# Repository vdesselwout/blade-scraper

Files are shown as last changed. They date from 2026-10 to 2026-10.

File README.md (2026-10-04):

<!-- Keep this README in step with the releases: see "Updating this README" at the bottom. -->

# Blade scraper

A 3D-printed razor scraper for standard trapezoid utility blades (61 mm cutting edge). Use it on glass, tiles, labels and paint. It has four PLA parts and needs no screws, other hardware or supports.

**Current version: v7** · [download the latest release](https://github.com/vdesselwout/blade-scraper/releases/latest) · [on Printables](https://www.printables.com/model/1865739-razor-blade-scraper-with-spare-blade-drawer-no-scr) · v7 changes only the guard, which now holds on to the handle instead of the cap. v7 is test-printed: the guard slides on and holds, though it comes off a little easily

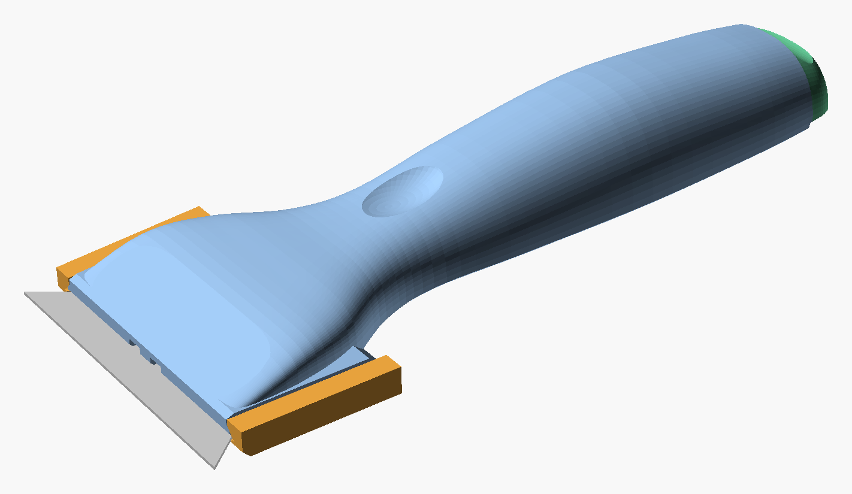
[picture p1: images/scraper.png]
The scraper with a blade fitted


| Guard on | Spare-blade drawer open |
|---|---|
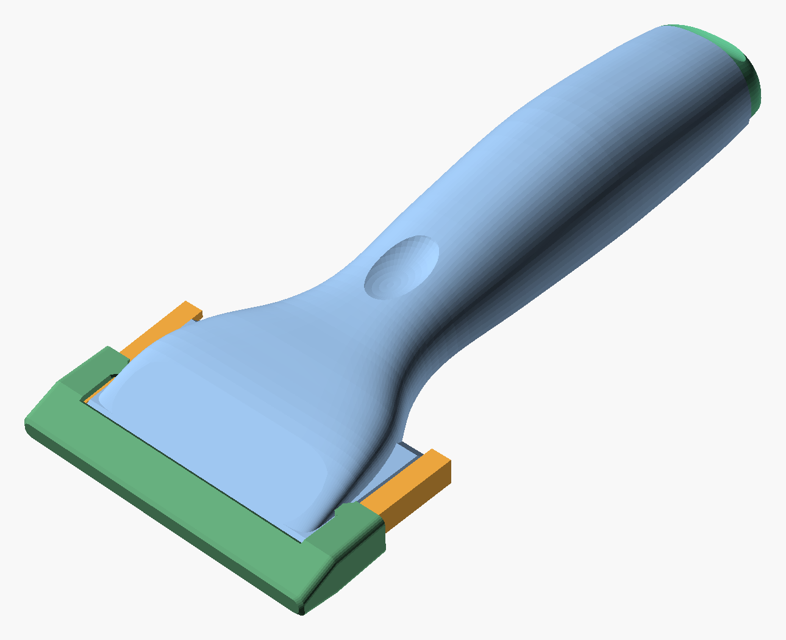
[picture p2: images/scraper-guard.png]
The scraper with the open-top guard fitted
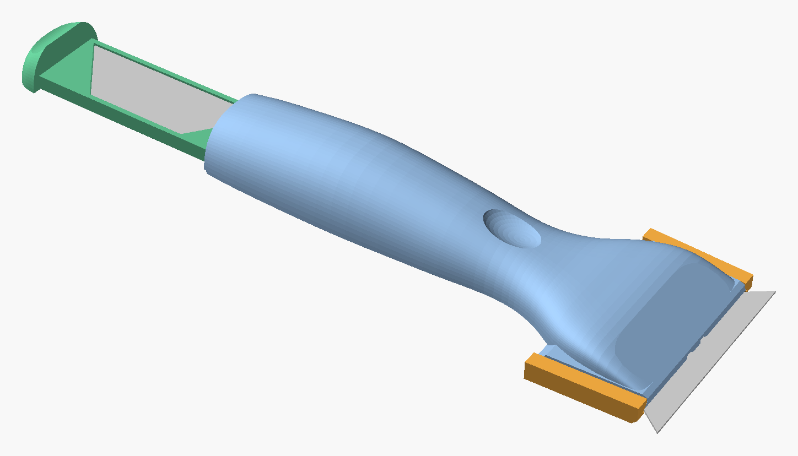
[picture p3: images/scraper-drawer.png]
The blade drawer pulled out of the handle, holding spare blades
|  |  |

## Features

- **No-tool blade change:** the blade sits on two pegs that go through its notches. The cap slides onto the head on dovetails and clamps the blade, and a small snap stops it creeping forward.
- **Spare blades in the handle:** a drawer slides out of the butt and holds 5 blades flat, with their edges enclosed. It "clicks" shut.
- **Slim guard:** an open-top guard covers the exposed edge and leaves the head visible. It grips the head, not the cap, so taking it off never pulls the cap and blade with it.
- **Size:** 155.5 mm long, with a 31 × 19 mm palm swell. The full set uses about 38 g of PLA.

## Printing

Each [release](https://github.com/vdesselwout/blade-scraper/releases) has three files:

- `scraper-vN.stl`: all parts laid out on one bed
- `scraper-vN.3mf`: the same layout as a Creality Print project, with print settings included
- `scraper-vN-parts.zip`: each part as its own STL

Print in PLA with a 0.4 mm nozzle, 2 walls and 15% infill. Print every part as laid out; no supports are needed. The guard stands on its nose with its open end up; if it comes loose from the bed, turn on a brim. The only bridges are short ones: the two 3.4 mm peg grooves under the head and the 23 mm roof of the drawer channel in the handle.

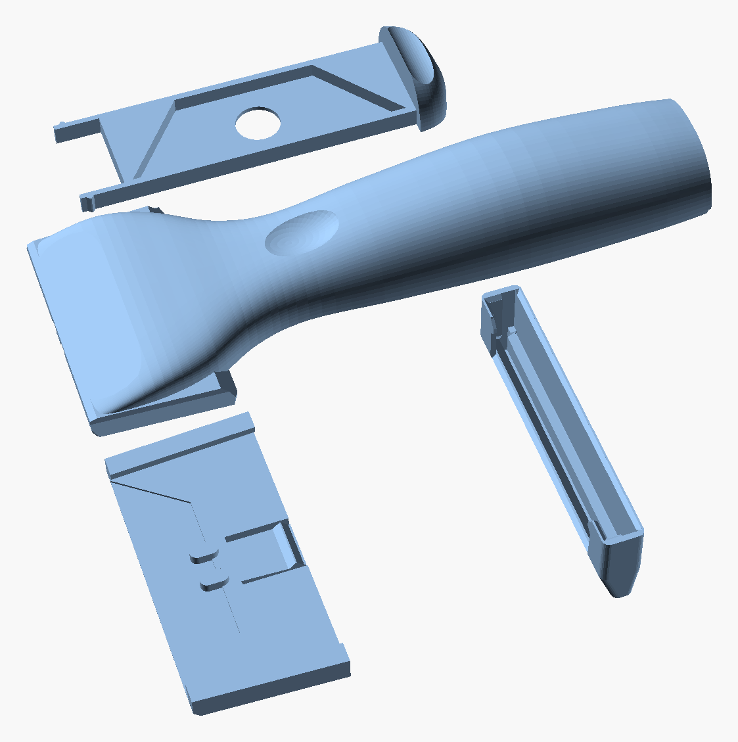
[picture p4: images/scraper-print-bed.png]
All four parts laid out for printing


v6 printing on a Creality K2 Pro:

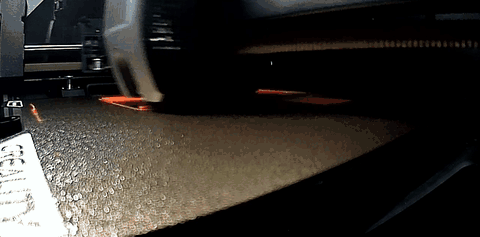
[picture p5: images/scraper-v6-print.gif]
Timelapse of the v6 parts printing on a Creality K2 Pro


Already printed v6? Only the guard changed in v7, so you just need to reprint the guard.

## Using it

1. **Fitting a blade:** lay the blade in the cap's pocket with the notches over the pegs and the cutting edge facing forward. Slide the cap backwards onto the head until it "clicks" into place or cannot slide any further.
2. **Removing a blade:** pull the cap firmly forward off the head.
3. **Spare blades:** pull the drawer out of the butt by the groove on its end. Push the stack up through the hole in the tray floor to take the top blade.

## Versions

| Version | What changed |
|---|---|
| [v7](https://github.com/vdesselwout/blade-scraper/releases/tag/v7) | Guard grips the head instead of the cap, so taking it off carelessly can no longer take the cap with it |
| [v6](https://github.com/vdesselwout/blade-scraper/releases/tag/v6) | Open-top guard, 8.4 mm tall instead of 13.7 |
| [v5](https://github.com/vdesselwout/blade-scraper/releases/tag/v5) | Shorter, slimmer handle with a spare-blade drawer; head flows into the grip |
| [v4](https://github.com/vdesselwout/blade-scraper/releases/tag/v4) | Tapered dovetails, so fitting the cap no longer drags the blade out |
| [v3](https://github.com/vdesselwout/blade-scraper/releases/tag/v3) | Guard clears the cap's flared first layers |
| [v2](https://github.com/vdesselwout/blade-scraper/releases/tag/v2) | Guard's blade slot runs through to the mouth |
| [v1](https://github.com/vdesselwout/blade-scraper/releases/tag/v1) | First version |

[REVIEW.md](REVIEW.md) has the full log of what changed and why.

## Repository

- `scraper-vN.scad`: the OpenSCAD model of each version. Use a nightly OpenSCAD build; the parts are selected with `part_sel`.
- `drawings/`: a dimensioned drawing and renders for each version
- `prints/`: print files and test-fit pieces for each version
- `concepts/`: design studies that led to v5 and v6
- [BRIEF.md](BRIEF.md): requirements and how the blade is held
- `tools/`: helper scripts (Creality Print project builder, README renders)

## Licence

[CC BY-NC-SA 4.0](https://creativecommons.org/licenses/by-nc-sa/4.0/): you may print, share and remix this design for non-commercial use, as long as you credit it and release remixes under the same licence. See [LICENSE](LICENSE).

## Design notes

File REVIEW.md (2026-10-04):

# Blade scraper — review log

Approved version: **v7** (2026-10-04, guard test-printed; earlier: v1 on 2026-10-03); v3 guard (fits the printed v1) and v4 tapered dovetails pending test prints; v5 (new handle, blade drawer) and v6 (open-top guard) pending review. Print files are in prints/vN/: v1 body, cap, test-fit piece and the sliced gcode; v3 guard (plus all three parts with the v3 guard); v4 all parts and test-fit project; v5 all four parts and the drawer test-fit project; v6 all four parts, the guard on its own and the guard test-fit project; v7 the same (only the guard changed). Design concepts are in concepts/.

| Version | Changes | Why | Verdict |
|---|---|---|---|
| v1 | First model: body with rising D-section handle, slide-on cap with pegs + 45° dovetails + snap tab, slide-on guard, test-fit piece | Design brief | approved |
| v2 | Guard: the 62 mm blade slot now runs through to the mouth; friction bumps moved above the slot | The guard's mouth was only 59 mm wide, narrower than the 61 mm cutting edge that has to pass through it, so the guard couldn't slide on | reviewed: folded into v3 before printing |
| v3 | Guard: walls relieved to the blade slot's width below the slot; 0.8 mm lead-in chamfer at the mouth | The cap's flared first layers (elephant's foot) caught on one side, and the mouth's own first layers narrow the opening | pending: test print |
| v4 | Tapered dovetails: head and cap widen 0.05 mm per mm per side towards the back (cap 58.5 mm at the front as before, 61.5 mm at the back); guard follows the wider cap | Sliding the cap on dragged the blade out of the pocket: the clamp was tight over the whole travel and nothing stops the blade moving forward. Now the lips only touch in the last 2 mm | pending: test-fit print |
| v5 | New handle: 155.5 mm overall (was 177), 31 × 19 mm palm swell, one smooth spline. Head above the cap lofted into the grip; below 3.6 mm and under the guard it is v4's exactly, so cap and guard are unchanged. Blade drawer: a tray for 5 spare blades slides in from the butt and clicks shut on two side-flexing arms. Drawer test-fit piece | User wanted it sleeker, shorter and lighter on filament, safe storage for spare blades, and a head that flows into the handle. Chosen from the v5 concept study (concept 2 with the flowing head) | pending: review, then drawer test-fit print |
| v6 | Open-top guard: closed only over the exposed blade, then a frame whose rails hook over the cap walls with the head showing through. 8.4 mm tall (was 13.7), walls 1.2 mm (was 1.6), 4.6 g (was 7.7). Inside fit unchanged: blade slot, cap clearance, friction bumps, mouth lead-in. Guard test-fit piece (head front, cap, guard). Fixed in place after release: the guard prints standing on its nose (flat 0.6 mm-chamfered nose) instead of its open end, where the open top's front edge and the end of the blade slot were 51 and 62 mm bridges | User wanted a sleeker guard to match the v5 head, then a slimmer wedge; chose the open top from the guard concept study | pending: guard test-fit print |
| v7 | Guard only: the two friction bumps on the cap walls are gone; instead a 45°-ended pad on each rail presses 0.35 mm into the head's flank above the cap (x 12.5–18, z 4.0–4.7, clear of the dovetail band). The guard now touches only the body, 0.3 mm clear of the cap all round. Body, cap and drawer unchanged from v6 | Taking the guard off often pulled the cap and blade with it, sometimes out of the guard: the guard gripped the cap, and the cap slides off in the same direction the guard is pulled | approved: test-printed 2026-10-04; slides on and holds, comes off a little easily but acceptable (`pad_interference` 0.45 would make it firmer) |

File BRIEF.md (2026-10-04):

# Design brief

A hand-held razor scraper for flat surfaces (glass, tiles, print beds, labels, paint), holding one standard trapezoid utility blade across the front of the handle. Printed in PLA, assembled without screws or other hardware.

| Requirement | Value | Source |
|---|---|---|
| Use | Flat-surface scraping at a low angle (about 15–35°), full cutting edge exposed | user |
| Blade | Trapezoid utility blade, 61 mm edge × 19 mm tall × 0.6 mm, two notches in the back edge, no holes | user / standard |
| Blade back edge | 31.6 mm, so each slanted side runs 14.7 mm sideways over 19 mm | measured from photo with ruler |
| Notches | 3.35 mm wide, 3.85 mm deep (to the tip of the round end), centres 6.65 mm apart, centred on the back edge | measured from photo with ruler (±0.2 mm) |
| Blade retention | Concept A: pegs in the notches, slide-on clamp cap with dovetail and snap | user |
| Blade exposure | 6 mm beyond the holder | user |
| Handle | Sleek, shorter, less filament than v4 (v5: 155.5 mm overall, D-section 31 × 19 mm at the palm swell), waist near the head, thumb/index-finger dish on top | user (v5) |
| Head shape | Flows smoothly into the grip; sole, dovetails, grooves and snap stay as v4 | user (v5) |
| Blade storage | Spare blades kept safely inside the handle: drawer from the butt, 5 blades flat, edges enclosed, clicks shut | user (v5) |
| Blade guard | Separate slide-on guard, as slim as possible to match the head (v6: open-top frame, 8.4 mm tall; closed only over the exposed blade) | user (v6) |
| Material / printer | PLA, 0.4 mm nozzle, bed ≥ 220 mm | user |
| Warping | Curved plan outline with no long straight walls, rounded ends, 0.6 mm bed chamfers; every part prints without supports | user |
| Hardware | None. Four printed parts: body, cap, guard, blade drawer | user |

## How the blade is held

Seen from the side, top to bottom: the body (head and handle), then the blade, then the cap. The surface being scraped is below the cap.

- **Cap (surface side):** a thin plate with a 0.6 mm blade-shaped pocket and two pegs that go up through the notches. Its side walls hook onto 45° dovetails on the sides of the head.
- **Changing the blade:** lay the blade in the cap, then slide the cap backwards onto the head until it clicks. The pegs run in two grooves under the head, and the end of each groove is the hard stop.
- **Load path:** scraping pushes the blade back into the pegs, the pegs push into the groove ends in the body, so the force goes straight into the handle and never through the snap.
- **Clamping:** the cap's dovetail lips overlap the head by 0.1 mm, so the cap walls have to spread slightly to slide on and then pull the cap up against the blade over its whole covered area (about 13 × 32–52 mm). The pocket is 0.45 mm deep for the 0.6 mm blade, so the cap never touches the body and all the clamping force goes through the blade. The only thing that stops the blade being pulled straight forward is this clamping friction, because the notches open towards the back.
- **Snap:** a flexible tab in the cap behind the blade has a bump that clicks into a 45° dimple under the head. It only stops the cap creeping forward. To release it, pull the cap firmly forward and the bump ramps out.
- **Surface clearance:** the cap is 1.6 mm thick under the blade, with a 45° chamfer at the front, so the scraper can be used down to about 12° from the surface.

## Why "cranked" becomes "rising handle"

The body prints on its flat underside, so the handle's underside has to stay on the bed: a real downward bend would need supports. Instead the grip's top rises from about 7 mm at the head to 19 mm at the palm swell (26 mm before v5), so the handle's centre line climbs like a crank while the underside stays flat. Held at a normal scraping angle, the underside lifts away from the surface along the whole length.

Interfaces
- Blade ↔ cap pocket: +0.25 mm clearance on the outline, pocket depth 0.45 mm (the blade stands 0.15 mm proud).
- Notches ↔ pegs: pegs Ø 3.0 mm (notch 3.35 mm), sitting against the round end of each notch.
- Pegs ↔ body grooves: groove 3.4 mm wide, 1.8 mm deep, open at the front, closed at the stop.
- Cap ↔ head dovetail: 45°, 2 mm high, 0.1 mm overlap that sets the clamping force.
- Guard ↔ head: friction fit over the cap walls, 0.3 mm clearance plus two small bumps. From v6 the guard is open over the head (opening = head band + 0.6 mm) and its rails hook over the cap walls. From v7 the guard grips the head, not the cap: a pad on each rail presses 0.35 mm into the head's flank above the cap, and the guard stays 0.3 mm clear of the cap all round, so pulling the guard off never drags the cap and blade with it (`pad_interference` tunes the grip).
- Drawer ↔ channel: 23 × 4.8 mm channel, 0.2 mm clearance per side and over the top.
- Drawer catch: two 10 × 1.2 mm arms flex sideways; 0.7 mm bumps click into 0.6 mm grooves in the channel walls (0.5 mm flex while sliding).

Out of scope / nice-to-have
- Adjustable blade exposure, hang hole, text or logo.

Assumptions to check
- Notch values come from a photo, so they're good to about ±0.2 mm. The first print is a small **test-fit piece** (the head plus cap, about 10 minutes) to check the pegs, pocket, dovetail and snap before printing the full handle.
- The 0.1 mm dovetail overlap (the clamping force) may need tuning on your printer. It's a single parameter, `clamp_interference`.
- The drawer catch force depends on the printer; `catch_h` (bump height) tunes it. The drawer test-fit piece (about 6 g) checks the sliding fit and the click.

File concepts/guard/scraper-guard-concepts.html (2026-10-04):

Blade scraper · guard study for v6 · 2026-10-04

# Guard concepts

New outer shapes for the blade guard, made to match the v5 head. The slimmer versions of the wedge are first; the original three concepts follow. Only the outside changes. Inside, every guard keeps the v4/v5 fit: the full-width blade slot, the clearance over the cap and head, the two friction bumps and the lead-in at the mouth.

changed: guard outside unchanged: fit on the cap unchanged: friction bumps unchanged: body, cap, drawer

Update · slimmer wedge

## Making the wedge slimmer

The wedge's height comes from what it has to cover: the cap underneath, and the head on top, which is 7.7 mm tall where the guard ends. Thinner walls only buy about a millimetre, so I tried three ways down, from a gentle trim to a different idea.

Guard | Height at the nose | Height at the mouth | Grip on the cap | Filament
Wedge (concept 1) | 5.0 mm | 14.5 mm | 12 mm | 6.4 g
Slim wedge | 4.2 mm | 13.3 mm | 12 mm | 6.0 g
Slim wedge, shorter | 4.2 mm | 12.1 mm | 9 mm | 5.1 g
Open top | 4.2 mm | 8.4 mm | 12 mm | 4.6 g

wedge · 14.5 mm

wedge · 14.5 mm, side view

slim wedge · 13.3 mm

slim wedge, shorter · 12.1 mm

slim wedge, shorter · 12.1 mm, side view

open top · 8.4 mm

open top · 8.4 mm, side view

Side views at the same scale. All three are checked in the model against the v5 body and blade: no overlaps. Inside they keep the same fit as before.

Slim 1

## Slim wedge

on the tool

Slim wedge guard fitted, close-up

side

guard, from the mouth

Slim wedge guard on its own

The same wedge with 1.2 mm walls instead of 1.6 (three printed lines, still solid) and a thinner, squarer crown over the head. Same length, same fit, same look, just tighter around the parts inside.

Length × height

20 mm; 4.2 mm at the nose, 13.3 at the mouth

Filament

6.0 g

Grip on the cap

12 mm, as now

#### Good

- No change in how it fits or prints
- Thinner nose, so the tip looks finer

#### Watch

- Only 1.2 mm lower than the wedge: the head under it is 7.7 mm tall at the mouth, and that sets the height
- Thinner side walls press the friction bumps a little less firmly

whole tool

Whole scraper with the Slim wedge guard

Slim 2

## Slim wedge, shorter

on the tool

Slim wedge, shorter guard fitted, close-up

side

guard, from the mouth

Slim wedge, shorter guard on its own

The slim wedge ending 3 mm sooner, at x = 15. The head is lower there, so the mouth drops with it. The friction bumps are still inside.

Length × height

17 mm; 4.2 mm at the nose, 12.1 at the mouth

Filament

5.1 g

Grip on the cap

9 mm

#### Good

- A clear step slimmer while still a closed wedge
- Still covers the whole front of the head

#### Watch

- A quarter less overlap with the cap, so a little more play

whole tool

Whole scraper with the Slim wedge, shorter guard

Slim 3

## Open top

on the tool

Open top guard fitted, close-up

side

guard, from the mouth

Open top guard on its own

The guard only has to cover the exposed 6 mm of blade. So behind the nose its top is cut away over the head: it becomes a slim frame that hooks over the cap side walls, and the sculpted head shows through. The blade edge is still fully enclosed.

Length × height

20 mm; 4.2 mm at the nose, 8.4 at the mouth

Filament

4.6 g

Grip on the cap

12 mm, as now

#### Good

- By far the slimmest: 8.4 mm instead of 14.5
- The head stays visible, so the tool keeps its shape with the guard on
- Still holds on the cap the same way: the friction bumps on the side walls, and rails over the cap lips

#### Watch

- A frame is less stiff than a closed shell; worth a test print to check it does not twist
- Dirt can get in over the head (not near the blade edge)

whole tool

Whole scraper with the Open top guard

First round

## The original concepts

Guard | Height at the nose | Height at the mouth | Grip on the cap | Filament | Prints
Current (v4) | 13.7 mm | 13.7 mm | 12 mm | 7.7 g | mouth down
1 · Wedge | 5.0 mm | 14.5 mm | 12 mm | 6.4 g | mouth down
2 · Raked | 5.0 mm | 15.5 mm | 9.5–15 mm | 6.6 g | on the slanted mouth
3 · Short sleeve | 5.0 mm | 12.2 mm | 6 mm | 4.6 g | mouth down

All three are checked in the model against the v5 body and blade: no overlaps. The guard can't get narrower than 65 mm, because the 61 mm cutting edge has to pass through its mouth on the way in, so all the slimming happens in height and in the shoulders. Filament is estimated the same way as for the handle (2 walls, 15% infill).

Reference

## Current guard (v4)

on the tool

Current guard (v4) guard fitted, close-up

side

guard, from the mouth

Current guard (v4) guard on its own

A box with rounded corners, the full 13.7 mm mouth height from front to back. It does its job, but next to the new head it reads as a separate block.

Length × height

20 × 13.7 mm, same height everywhere

Filament

7.7 g

whole tool

Whole scraper with the Current guard (v4) guard

Concept 1

## Wedge

on the tool

Wedge guard fitted, close-up

side

guard, from the mouth

Wedge guard on its own

The top runs in one straight line from a thin 5 mm nose up to the mouth, so in profile the guard continues the head's rising line. Over the head it uses the head's own rounded-box section, and the sides fall away in soft shoulders instead of square edges.

Length × height

20 mm; 5 mm at the nose, 14.5 at the mouth

Filament

6.4 g (−1.3 g)

Grip on the cap

12 mm, as now

#### Good

- Reads as the tip of the tool, not a box on the end
- Same fit and same overlap with the cap as the guard you're testing
- Prints mouth-down like v4, no supports

#### Watch

- 0.8 mm taller than v4 at the mouth (the rounded crown needs a little more wall at its corners)

whole tool

Whole scraper with the Wedge guard

Concept 2

## Raked

on the tool

side

Raked guard, side view

guard, from the mouth

Raked guard on its own

The wedge with its mouth cut on a slant: shorter underneath, and reaching 3 mm further back over the head on top. From the side the back edge sweeps up the same way the head rises into the grip.

Length × height

17.5 mm underneath, 23 on top; 15.5 at the mouth

Filament

6.6 g (−1.1 g)

Grip on the cap

9.5 to 15 mm

#### Good

- The most dynamic side profile
- Covers more of the head, so it looks most like one piece with the tool

#### Watch

- Prints on its slanted mouth: one inside ramp gets steeper than 45° and needs checking in the real build
- The top back edge comes to a thin point that I'd blunt to about 1 mm

whole tool

Whole scraper with the Raked guard

Concept 3

## Short sleeve

on the tool

Short sleeve guard fitted, close-up

side

guard, from the mouth

Short sleeve guard on its own

The wedge cut down to just past the friction bumps. It covers the exposed 6 mm of blade and 6 mm of the cap, and nothing more.

Length × height

14 mm; 5 mm at the nose, 12.2 at the mouth

Filament

4.6 g (−3.1 g)

Grip on the cap

6 mm

#### Good

- Lightest and most compact
- Smallest thing to lose in a drawer

#### Watch

- Half the overlap with the cap, so it can rock more and is easier to knock off
- Least of the sweep that makes concept 1 match the head

whole tool

Whole scraper with the Short sleeve guard

Recommendation

## Open top, or the shorter slim wedge

If you want it properly slim, the open top is the only one that changes the proportions: it is 8.4 mm tall instead of 14.5, lets the head show, and keeps the same 12 mm hold on the cap. It deserves a quick test print to check it is stiff enough. If you'd rather keep a closed wedge, the shorter slim wedge is 2.4 mm lower than the wedge for a little less overlap.

Pick one and I'll build it into v6 with drawings, renders and a test print of the guard.

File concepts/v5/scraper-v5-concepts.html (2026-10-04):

Blade scraper · v5 handle study · 2026-10-04

# Scraper v5 concepts

Four new handle shapes, all shorter and lighter than v4. Only the handle changes. The head, cap, dovetails, snap and guard are v4's exactly, so the v4 test-fit print still counts for all of them.

changed: handle shape unchanged: head + dovetails unchanged: cap + pegs + snap unchanged: guard still no hardware, no supports

## At a glance

Concept | Overall length | Palm swell (w × h) | Body | Full print set | Holds spare blades
v4 (current) | 177 mm | 33 × 26 mm | 30.4 g | 42.7 g | no
1 · Slim | 150 mm −27 | 30 × 21 mm | 21.4 g | 33.7 g −21% | no
2 · Blade drawer | 156 mm −21 | 31 × 19 mm | 23.2 + 5.2 g | 40.8 g −4% | 5 blades
3 · Skeleton | 152 mm −25 | 32 × 20 mm | 21.0 g | 33.3 g −22% | no
4 · Low paddle | 148 mm −29 | 37 × 16 mm | 21.0 g | 33.4 g −22% | no

Filament is estimated from each model's volume and surface area with your slicer settings (2 walls, 15% infill). Checked against the v1 gcode: the model predicts 42.7 g, the slicer said 42.5 g. The set is body + cap (4.7 g) + guard (7.7 g), plus the drawer for concept 2. Overall length runs from the cutting edge to the butt.

Reference

## v4 (current)

iso

v4 (current): 3D view with cap and blade

side

top

v4 (current): top view

Today's handle, for scale. Every view on this page uses the same camera and scale, so you can compare lengths and heights directly.

Overall length

177 mm

Palm swell

33 × 26 mm

Body

30.4 g

Print set

42.7 g

Concept 1

## Slim

iso

Slim: 3D view with cap and blade

side

top

Slim: top view

The v4 layout redrawn as one smooth spline: the waist behind the head flows into a palm swell that is 5 mm lower and 3 mm narrower, and the handle ends 27 mm sooner in a rounded tail. Same hold as v4: palm over the swell, index finger in the dish.

Overall length

150 mm

Palm swell

30 × 21 mm at 102 mm

Grip behind the waist

≈100 mm

Body

21.4 g

Print set

33.7 g (−21%)

#### Good

- Lowest-risk change: same grip, same print
- Visibly sleeker side profile, no facets between stations
- Biggest saving for the least new geometry

#### Watch

- Large hands may overhang the tail slightly
- No storage

Concept 2

## Blade drawer

iso

Blade drawer: 3D view with cap and blade

side

top

Blade drawer: top view

Concept 1's proportions with a constant-section channel inside the grip. A tray holding 5 spare blades slides in from the butt, and its end piece forms the handle's tail. The grip is 2 mm flatter than concept 1 because the channel needs a steady cross-section.

Overall length

156 mm (drawer in)

Palm swell

31 × 19 mm at 104 mm

Storage

5 blades, fully enclosed

Body + drawer

23.2 + 5.2 g

Print set

40.8 g (−4%)

#### Good

- Spare blades always with the tool, edges enclosed
- Drawer end doubles as a smooth butt
- Still shorter and lighter than v4

#### Watch

- Smallest filament saving (the drawer and channel walls cost about 7 g)
- One more part, and the detent needs tuning

Concept 3

## Skeleton

iso

Skeleton: 3D view with cap and blade

side

top

Skeleton: top view

A slightly fuller slim handle with an 11 mm window through the grip. All its edges get 45° chamfers, so it prints without supports and doesn't leave a sharp rim under the palm.

Overall length

152 mm

Palm swell

32 × 20 mm, window 11 × 59 mm

Body

21.0 g

Print set

33.3 g (−22%)

#### Good

- The most distinctive look
- Window doubles as a hang hole (a nice-to-have from the brief)

#### Watch

- Saves only 0.4 g over concept 1: the window removes infill but adds wall
- Palm rests on two rims, not one dome
- Rules out the blade drawer

Concept 4

## Low paddle

iso

Low paddle: 3D view with cap and blade

side

top

Low paddle: top view

A wide, flat pebble only 16 mm tall, like a commercial glass scraper. The palm pushes down on a broad top, and a shallow saddle across the neck takes the index finger.

Overall length

148 mm

Palm swell

37 × 16 mm at 98 mm

Body

21.0 g

Print set

33.4 g (−22%)

#### Good

- Shortest and flattest
- Hand sits lower, close to the work, for very flat scraping angles
- Room inside for a drawer if wanted

#### Watch

- Less to wrap the fingers around for hard pulling strokes
- Biggest departure from the v4 feel

Your question

## Storing spare blades in the handle

Yes. The blades lie flat: 61 mm along the handle and 19 mm across it, which fits inside a 31 mm wide grip with 2 mm walls each side. Stood on edge they would need a 23 mm tall handle, which is taller than any of the new concepts.

drawer pulled out

Concept 2 with the green drawer pulled out of the butt, showing a blade in the tray

### How the drawer works

1. A tray slides into a 23 × 4.8 mm channel that runs 66 mm into the handle from the butt. The drawer's end piece is the rounded tail of the handle.
2. The tray pocket is blade-shaped, so the blades can't shift. Their cutting edges sit against the tray's solid side wall, never at the open side.
3. 5 blades stack 3 mm high in a 3.4 mm pocket. A 10 mm hole in the floor lets you push the stack up to pick off the top blade.
4. A small detent will hold the drawer shut (designed in v5, worth a quick test print). With the drawer in, the blades are fully enclosed.

Printing: the channel roof is a 23 mm bridge, which PLA handles without supports. The drawer prints flat on its floor.

### Other ways I looked at

Option | Why not
Hatch on the underside | The underside is where your fingers wrap. A seam or latch there is felt every stroke, and the lid can be knocked open.
Blades on edge in a slot | Needs a handle at least 23 mm tall along the whole slot, which works against the slimmer shapes.
Magnet in the handle | Needs hardware, which the brief rules out, and leaves the edges exposed.
Clip on the guard | Possible, but then the spares are only with you when the guard is on. Easy to add later on top of any concept.

The drawer can go into concept 1 or 4 too. It doesn't fit with concept 3, because the window takes the space the channel needs.

Recommendation

## Concept 2, the blade drawer

It keeps the v4 way of holding the tool, at 21 mm shorter, with a lower and smoother profile, and it adds safe blade storage while still using about 2 g less filament than v4. If storage turns out not to matter, concept 1 is the same shape without the drawer and saves the most for the least risk (about 9 g).

Once you pick one I'll build it as v5 with the drawing sheet, renders, review row and report, plus a small test-fit piece for the drawer detent.

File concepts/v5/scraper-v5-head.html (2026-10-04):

Blade scraper · v5 concept 2, revision b · 2026-10-04

# A head that flows into the grip

The blade-drawer concept with its head reshaped. The flat-topped block is gone: above the cap, the head is now one smooth surface that sweeps from the full blade width into the waist of the handle. Everything the blade, cap and guard touch is exactly as in v4.

changed: head above the cap unchanged: sole, dovetails, pegs, snap unchanged: guard fit unchanged: blade drawer

## Before and after

before · front three-quarter

Concept 2 head, front three-quarter

after · front three-quarter

Flowing head, front three-quarter

before · from behind

Concept 2 head, from behind

after · from behind

Flowing head, from behind

before · side

Concept 2 head, side

after · side

Flowing head, side

Before: a 53 mm wide box with a square back, with the grip attached behind it. After: the box's top corners are rounded off, its back sweeps into the waist in one curve, and the top rises 1.5 mm into the neck instead of stepping. The thumb dish moved 4 mm back so it sits on the new neck.

## How it keeps working

The head is split 3.6 mm above the sole, which is 0.4 mm above the top of the cap's lips. Below that line nothing changed. Above it the shape is free, with one exception: under the guard (the front 18 mm), the new top may not rise above v4's nose slope.

Feature | What happens to it
Sole under the blade | Same flat face, same 0.45 mm pocket, same clamping through the blade. | identical
Tapered 45° dovetails | Kept over the full length of the cap. The 0.05 mm/mm taper and the 0.1 mm clamp in the last 2 mm of travel are unchanged. | identical
Peg grooves and hard stop | Untouched. They are 1.8 mm deep, well below the 3.6 mm split. | identical
Snap dimple | Untouched (0.7 mm deep, 34 mm back from the edge). | identical
Guard | Same part, no changes. I checked the guard against the new head in the model: they don't overlap anywhere. | checked
Behind the cap | The dovetail plate used to stick out 2 mm behind the cap with square corners. It now stops 0.5 mm behind the cap, with rounded corners and a 45° back edge. | tidier
Printing | Still flat on the sole with no supports. The surface only narrows going up, so there are no overhangs. | same
Strength | The neck is wider and deeper where it meets the head. Before, there was a sharp inside corner there, which is where a PLA handle would crack first. | better

Concept 2b

## The whole tool

iso

Flowing-head drawer scraper, 3D view

side

top

Top view

with the guard on

Flowing-head scraper with the v4 guard fitted over the blade

The grip, the blade drawer and the overall length are the same as concept 2. Only the front 60 mm changed.

Overall length

156 mm (v4: 177)

Palm swell

31 × 19 mm

Storage

5 blades, enclosed

Body + drawer

23.1 + 5.2 g

Print set

40.7 g (v4: 42.7)

drawer pulled out

Drawer pulled out of the butt with spare blades in the tray

Still boxy

## The cap and the guard

With the head smoothed, the orange cap's square back corners stand out more. I left the cap alone on purpose: it clamps in its last 2 mm of travel, right at those corners, so rounding them would weaken the clamp you're about to test. Once the v4 test-fit print confirms the clamp, a 1 mm chamfer on the cap's outer top edges is a safe cosmetic change. The guard could get the same treatment.

Next: if you like this head, I'll build it as v5, with the drawing sheet, renders, review row, report and a test-fit piece for the drawer catch.

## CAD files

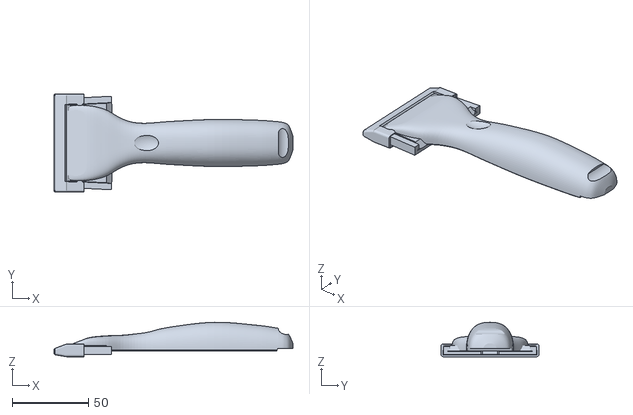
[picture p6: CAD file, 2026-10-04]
drawings/v7/assembled-guard-scraper-v7.stl
157.2 x 64.4 x 22.7

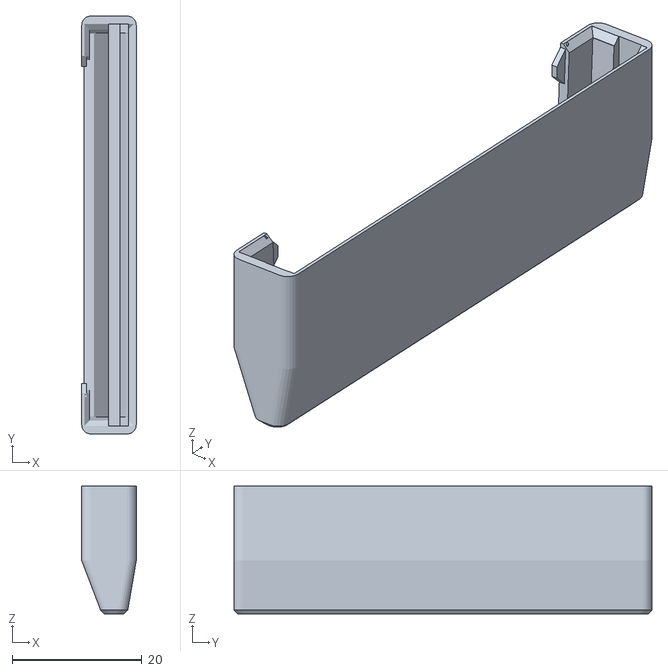
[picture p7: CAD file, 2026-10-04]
drawings/v7/guard-scraper-v7.stl
8.40 x 64.4 x 19.7

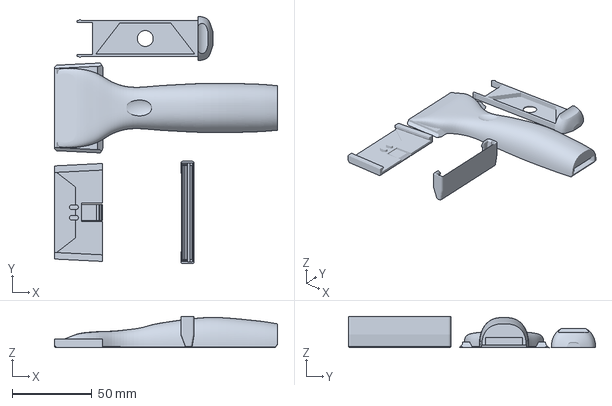
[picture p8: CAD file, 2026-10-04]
prints/v7/scraper-v7.3mf
140.0 x 155.4 x 19.7 mm

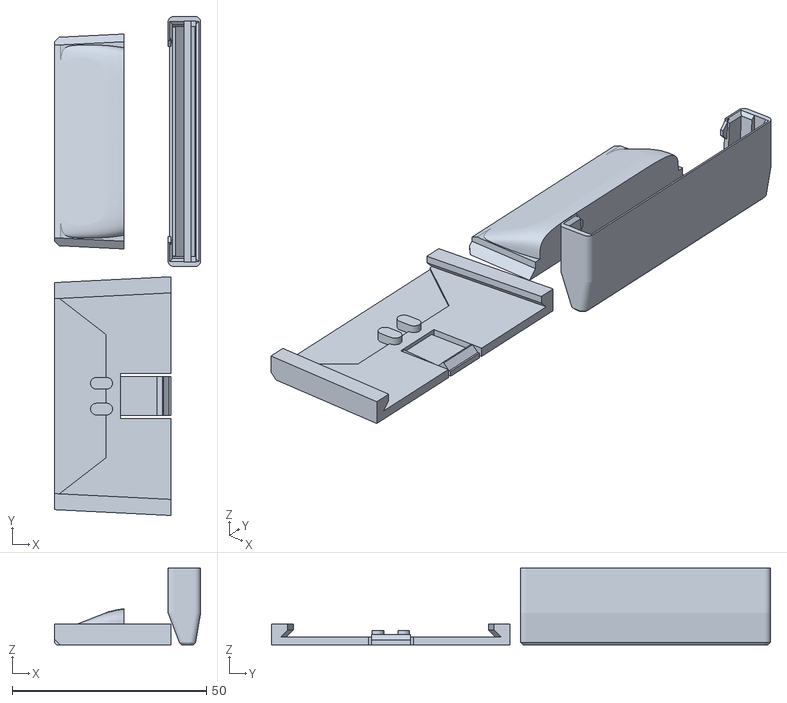
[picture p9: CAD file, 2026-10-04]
drawings/v7/guard-test-scraper-v7.stl
37.7 x 128.6 x 19.7

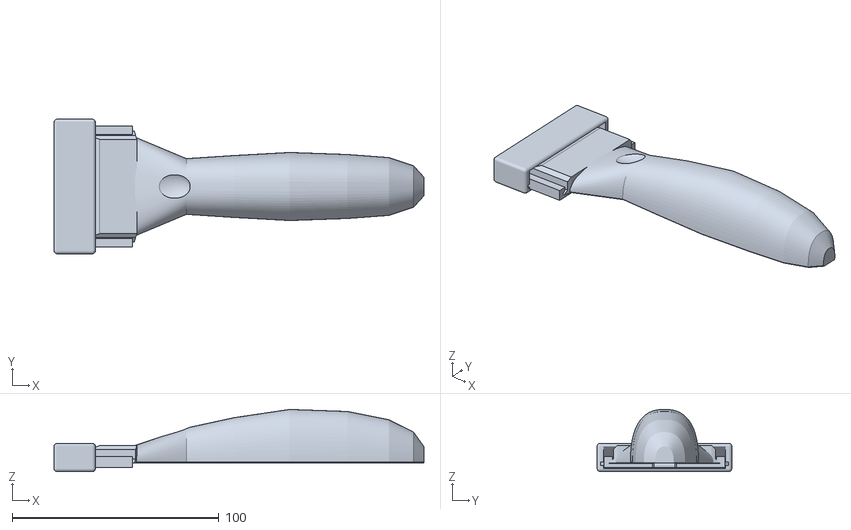
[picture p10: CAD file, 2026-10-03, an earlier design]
drawings/v2/assembled-guard-scraper-v2.stl
179.1 x 65.2 x 30.1

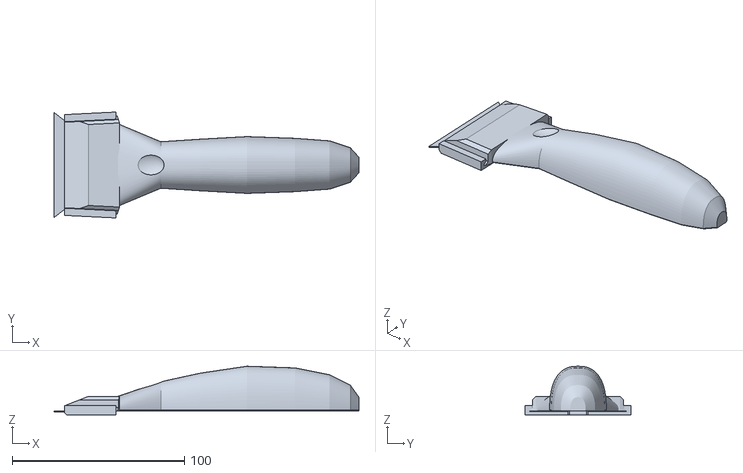
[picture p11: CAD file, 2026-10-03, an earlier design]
drawings/v4/assembly-scraper-v4.stl
177.0 x 61.5 x 28.2

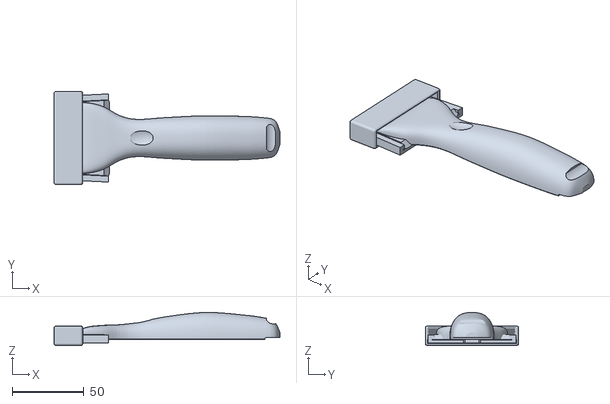
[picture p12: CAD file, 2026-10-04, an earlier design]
drawings/v5/assembled-guard-scraper-v5.stl
157.6 x 65.2 x 23.1

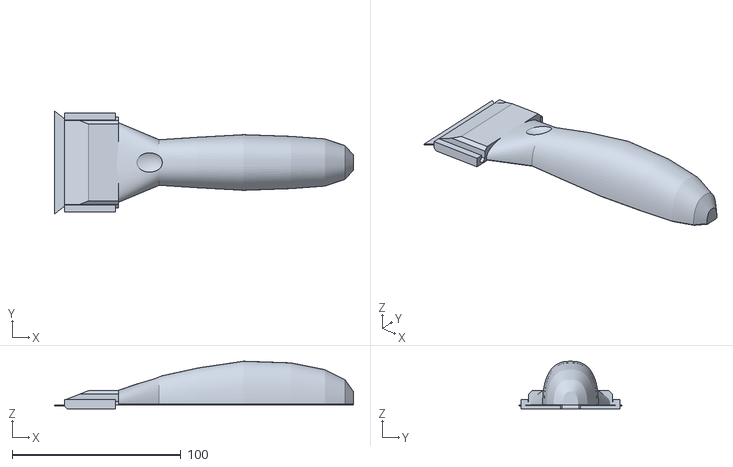
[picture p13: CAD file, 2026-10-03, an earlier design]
drawings/v1/assembly-scraper-v1.stl
177.0 x 61.0 x 28.2

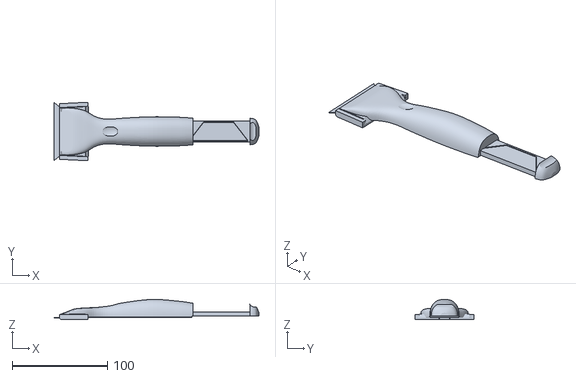
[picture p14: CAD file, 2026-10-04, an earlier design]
drawings/v6/assembly-open-scraper-v6.stl
215.5 x 61.5 x 21.2

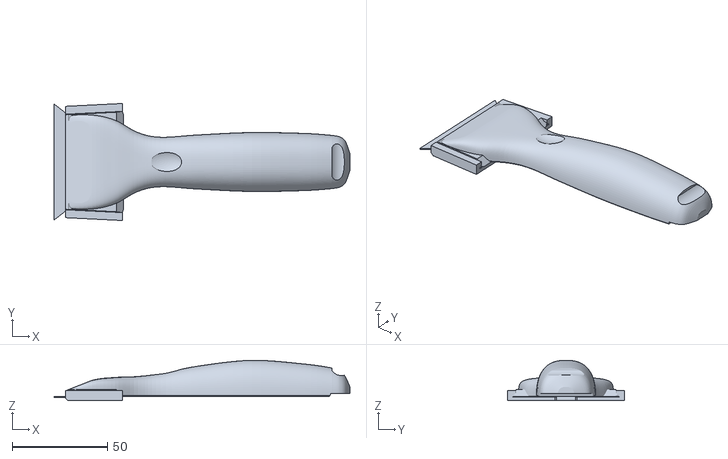
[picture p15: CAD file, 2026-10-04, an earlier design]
drawings/v6/assembly-scraper-v6.stl
155.5 x 61.5 x 21.2

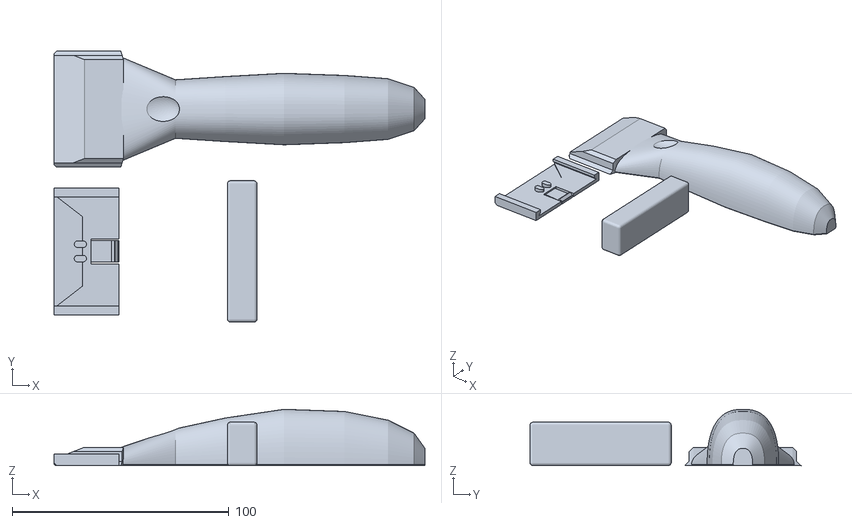
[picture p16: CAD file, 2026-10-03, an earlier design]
drawings/v1/scraper-v1.stl
171.0 x 125.0 x 26.0

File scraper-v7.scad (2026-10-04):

// Razor scraper for a trapezoid utility blade - v7
// v2: guard's blade slot runs through to the mouth (the 61 mm edge couldn't pass the 59 mm mouth)
// v3: guard relieved below the slot + mouth chamfer (it caught on the cap's elephant's foot)
// v4: tapered dovetails (head and cap widen 0.05 mm/mm per side towards the back): the cap only
//     clamps in the last 2 mm of travel, so the head no longer drags the blade out while it slides on
// v5: new handle, 21 mm shorter (156 mm overall), lower and slimmer (31 x 19 mm palm swell), one smooth
//     spline instead of hulled stations: user wants it sleeker, shorter and lighter on filament.
//     Blade drawer: 5 spare blades lie flat in a tray that slides into the grip from the butt and clicks
//     shut on a sprung tongue: user asked for safe blade storage in the handle.
//     Flowing head: above band_top the head is one loft from the blade width into the grip (the block
//     with a square back is gone): user wanted the head to flow into the handle. Everything below
//     band_top (sole, dovetails, grooves, snap dimple) and the nose under the guard are v4's exactly,
//     so cap and guard are unchanged.
// v6: open-top guard, 8.4 mm tall instead of 13.7: user wanted a sleeker guard to match the v5 head.
//     It closes only over the exposed blade; behind the nose it is a frame that hooks over the cap's
//     side walls and lets the head show through. Same inside fit as before (slot, cap zone, bumps,
//     mouth lead-in); walls 1.6 -> 1.2 mm.
//     Fixed in place: the guard prints nose down with a flat nose (printed mouth down, the open top's
//     front edge and the end of the blade slot were 51-62 mm bridges).
// v7: the guard grips the head, not the cap: pulling the guard off dragged the cap (and the blade) with
//     it, because its friction bumps pressed on the cap walls and the cap comes off in the same direction.
//     The bumps are gone; a pad on each rail presses on the head's flank above the cap instead, so
//     pulling the guard puts no load on the cap. Guard only: body, cap and drawer are v6's.
// Four printed parts, no hardware: body (handle + head), cap (holds the blade), guard, blade drawer.
// Axes (use = print orientation of the body): X along the tool, cutting edge at x = 0,
// handle towards +X. The blade lies in z = -0.6..0, the body sits on top (z >= 0), the cap below.
// The cap slides onto the head from the front (towards +X) on 45 deg dovetails; its pegs run in
// two grooves under the head and stop at the groove ends, which take the scraping force.

/* [Part] */
part_sel = "all"; // [all, body, cap, guard, drawer, test, drawer_test, guard_test, assembly, assembly_guard, assembly_open]

/* [Blade (measured)] */
blade_edge = 61;        // cutting edge length
blade_back = 31.6;      // back (notched) edge length
blade_h = 19;           // edge to back edge
blade_t = 0.6;
notch_w = 3.35;
notch_depth = 3.85;     // back edge to tip of the round end
notch_pitch = 6.65;     // centre to centre

/* [Fit] */
pocket_clear = 0.25;    // blade outline clearance in the cap pocket
pocket_depth = 0.45;    // < blade_t: cap top stays clear of the body sole
peg_d = 3.0;            // pegs in the notches
groove_w = 3.4;         // peg grooves under the head
groove_depth = 1.8;
clamp_interference = 0.1; // dovetail overlap; the cap walls spread this much and clamp the blade
guard_clear = 0.3;

/* [Head and cap] */
exposure = 6;           // blade beyond the holder
dt = 2.0;               // dovetail height (45 deg)
hw0 = 26.8;             // head half width at the sole (widest point of the dovetail)
head_end = 38;
head_h = 8.5;
nose_h = 3.0;           // head height at the front edge
cap_floor_t = 1.6;      // cap under the blade
cap_wall_t = 2.4;
cap_end = 36;
lip_top = dt + 1.2;
dt_taper = 0.05;        // dovetail widening per mm towards the back, each side
front_chamfer = 1.4;    // underside of the cap nose: surface clearance

/* [Snap] */
tab_w = 10;
tab_x0 = 23;
tab_t = 1.2;
bump_x = 34;
bump_h = 0.45;          // above the sole
dimple_depth = 0.7;

/* [Handle] */
// control stations [x, width, height, section exponent]: 10 = boxy (head), 2.5 = D-section (grip).
// A Catmull-Rom spline runs through them; under the guard (x < 20) it is clipped to v4's nose slope.
cp = [[6, 49.4, 3.0, 10], [20, 49.4, 8.5, 8], [32, 44, 10, 5], [44, 31, 10.5, 3.5], [56, 26, 12, 2.8],
      [76, 28.5, 16, 2.5], [104, 31, 19, 2.5], [132, 30, 17, 2.5], [146, 28, 15, 2.5]];
// drawer tail: continues the body's last station
tail = [[146, 28, 15, 2.5], [150, 26.5, 13.5, 2.5], [153, 22, 10.5, 2.5], [155.5, 9, 5, 2.5]];
band_top_over = 0.4;    // the head keeps v4's exact shape up to this far above the cap's lips
dish_x = 56;            // thumb / index-finger dish
bed_chamfer = 0.6;
smooth_fn = 64;

/* [Blade drawer] */
ch_x0 = 69;             // channel in the grip, open at the butt
ch_x1 = 146;
ch_w = 23;
ch_z0 = 1.6;            // channel floor above the bed
ch_h = 4.8;
drawer_clear = 0.2;     // per side, and over the top
tray_x0 = 80;           // tray front face (home position)
tray_floor = 1.0;
spare_n = 5;
spare_clear = 0.3;      // blade outline clearance in the tray pocket
push_hole_d = 10;
// catch: two arms run forward from the tray's front corners and flex sideways (in the print plane, so
// no overhang); a bump on each clicks into a vertical groove in the channel side wall
arm_l = 10;
arm_t = 1.2;            // arm thickness (y)
catch_x = 72;           // bump / groove position
catch_h = 0.7;          // bump height beyond the tray side
dimple_d = 0.6;         // groove depth into the channel wall

/* [Guard] */
guard_t = 1.2;          // three printed lines
guard_back = 12;
mouth_chamfer = 0.8;
// grip pads on the rails, pressing on the head's flank above the cap (not on the cap: see v7)
head_flank_hw = 24.8;   // head half width at z 4.0..4.7, x 15..17 (sliced from the body)
pad_interference = 0.35;
pad_x0 = 12.5;           // pad from x0 to x1, 45 deg ends
pad_x1 = 18;
pad_z0 = 4.0;           // up to the rail top; stays clear of the wider dovetail band below band_top

// ---------- derived ----------
side_run = (blade_edge - blade_back) / 2;           // 14.7
x_front = exposure;                                  // holder front edge
function blade_hw(x) = blade_edge / 2 - side_run * x / blade_h;
x_pc = blade_h - notch_depth + notch_w / 2;          // centre of the notch's round end
peg_rear = blade_h + 0.5 + peg_d / 2;                // pegs run back past the blade's back edge
groove_end = peg_rear + 0.05;
cap_z0 = -blade_t - cap_floor_t;                     // cap underside
cap_top = -blade_t + pocket_depth;
function hw(x) = hw0 + dt_taper * (x - x_front);     // head half width at the sole
function cap_hw_at(x) = hw(x) - clamp_interference - cap_top + cap_wall_t;
cap_hw = cap_hw_at(x_front);                         // at the front; widest at cap_end
body_len = cp[len(cp) - 1][0];
total_len = tail[len(tail) - 1][0];
clear_angle = atan(cap_floor_t / (exposure + front_chamfer));
function body_top(x) = x < 20 ? nose_h + (x - x_front) * (head_h - nose_h) / (20 - x_front) : head_h;
band_top = lip_top + band_top_over;
tray_w = ch_w - 2 * drawer_clear;
tray_h = ch_h - 2 * drawer_clear;
tray_top = ch_z0 + tray_h;
pocket_c = (tray_x0 + ch_x1) / 2;                    // spare blade pocket centre (x)
arm_flex = catch_h - drawer_clear;                   // arm deflection while the drawer slides
arm_strain = 3 * arm_t * arm_flex / (2 * arm_l * arm_l);

echo(str("blade covered: ", blade_h - exposure, " mm, width at holder front ", 2 * blade_hw(x_front)));
echo(str("clamp engages in the last ", clamp_interference / dt_taper, " mm of travel"));
echo(str("cap width ", 2 * cap_hw, " front, ", 2 * cap_hw_at(cap_end), " back, body length ", body_len, ", surface clearance angle ", clear_angle));
echo(str("overall length ", total_len, " mm; drawer catch: arms deflect ", arm_flex, " mm, strain ", 100 * arm_strain, " %"));
assert(hw0 + 0.05 > blade_hw(x_front) + pocket_clear + 0.5, "cap wall cuts into the pocket");
assert(pocket_depth < blade_t, "cap top would touch the sole: no clamping");
assert(peg_d < notch_w, "pegs too big for the notches");
assert(total_len < 220, "body longer than the bed");
assert(g_cap_hw(x_front + guard_back) + mouth_chamfer < g_hw, "guard mouth chamfer cuts into the wall");
assert(spare_n * blade_t + 0.3 < tray_h - tray_floor, "spare blades don't fit the pocket depth");
assert(blade_edge + 2 * spare_clear + 2 < ch_x1 - tray_x0, "tray too short for the spare blades");
assert(blade_h + 2 * spare_clear + 2.5 < tray_w, "tray too narrow for the spare blades");
assert(pad_z0 - guard_clear > band_top, "guard pads can reach the dovetail band");
assert(arm_flex > 0.3 && arm_strain < 0.015, "drawer catch too weak or overstrained");
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

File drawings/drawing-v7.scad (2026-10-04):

// Dimensioned drawing sheet for scraper-v7: the guard grips the head, not the cap.
use <../scraper-v7.scad>

flat = false;
module ex(h) if (flat) children(); else linear_extrude(h) children();
module model() scraper("assembly");

lw = 0.3;
ts = 3.2;

module seg(a, b, w = lw) hull() { translate(a) circle(d = w, $fn = 8); translate(b) circle(d = w, $fn = 8); }
module arrow(p, dir) translate(p) rotate(dir) polygon([[0, 0], [-2.2, 0.7], [-2.2, -0.7]]);
module label(p, s, rot = 0, h = "center") translate(p) rotate(rot) text(s, size = ts, halign = h, valign = "center", font = "Liberation Sans");
module dim_h(x1, x2, y, s, ye) {
    if (ye != undef) { seg([x1, ye], [x1, y + (y > ye ? 1 : -1)]); seg([x2, ye], [x2, y + (y > ye ? 1 : -1)]); }
    seg([x1, y], [x2, y]); arrow([x1, y], 180); arrow([x2, y], 0);
    label([(x1 + x2) / 2, y + 2.8], s);
}
module dim_v(y1, y2, x, s, xe) {
    if (xe != undef) { seg([xe, y1], [x + (x > xe ? 1 : -1), y1]); seg([xe, y2], [x + (x > xe ? 1 : -1), y2]); }
    seg([x, y1], [x, y2]); arrow([x, y1], 270); arrow([x, y2], 90);
    if (s != "") label([x - 2.8, (y1 + y2) / 2], s, 90);
}
module leader(from, to, s, h = "left") {
    seg(from, to); arrow(from, atan2(from.y - to.y, from.x - to.x));
    label(to + [h == "left" ? 1.5 : -1.5, 0], s, 0, h);
}
module clip(x0, y0, w, h) intersection() {
    children();
    if (flat) translate([x0, y0]) square([w, h]); else translate([x0, y0, -1]) cube([w, h, 3]);
}

module ann() if (flat) children(); else translate([0, 0, 0.3]) children();
module cut_xz(y0) projection(cut = true) translate([0, 0, y0]) rotate([-90, 0, 0]) children();
module cut_yz(x0) projection(cut = true) translate([0, 0, -x0]) rotate([-90, 0, 0]) rotate([0, 0, -90]) children();
// body light grey, cap orange, blade black, drawer green, spare blades dark grey
// body light grey, cap orange, blade black, guard green
module parts() {
    color("#c4c4c4") ex(0.1) children(0);
    color("#e8a33d") translate([0, 0, 0.02]) ex(0.1) children(1);
    color("#222222") translate([0, 0, 0.04]) ex(0.1) children(2);
    color("#5cb88a") translate([0, 0, 0.06]) ex(0.1) children(3);
}
module section_xz(y0 = 0) parts() { cut_xz(y0) body(); cut_xz(y0) cap(); cut_xz(y0) blade(); cut_xz(y0) guard(); }
module section_yz(x0 = 0) parts() { cut_yz(x0) body(); cut_yz(x0) cap(); cut_yz(x0) blade(); cut_yz(x0) guard(); }

// ================= SHEET =================
// A) section on the centre line through the guard, 3:1
{
    k = 3;
    scale(k) clip(-3, -5, 30, 15) section_xz(0);
    color("#000") ann() ex(0.2) {
        dim_h(-1.7 * k, 18 * k, -20, "19.7", -3.7 * k);
        dim_v(-2.4 * k, 1.8 * k, -16, "4.2", -1.7 * k);
        dim_v(-3.7 * k, 4.7 * k, 90, "8.4", 18 * k);
        leader([12 * k, 4.6 * k], [20, 40], "open over the head", "right");
        leader([3 * k, 1.8 * k], [-20, 30], "closed over the exposed blade", "right");
        label([-8, -32], "A: SECTION ON THE CENTRE LINE, 3:1", 0, "left");
    }
}
// B) cross section at x = 15.5 through the grip pads, 2:1
translate([170, 0]) {
    k = 2;
    scale(k) clip(-34, -5, 68, 14) section_yz(15.5);
    color("#000") ann() ex(0.2) {
        dim_h(-32.2 * k, 32.2 * k, -18, "64.4", -3.7 * k);
        dim_h(-24.45 * k, 24.45 * k, 22, "pads 48.9 (head 49.6)", 4.7 * k);
        leader([25.5 * k, 4.4 * k], [40, 36], "pads grip the head, not the cap", "left");
        label([-60, -30], "B: SECTION AT X = 15.5 (GRIP PADS), 2:1", 0, "left");
    }
}
// C) plan cut at z = 4.2 through the rails, 1:1
translate([20, -85]) {
    color("#5cb88a") ex(0.1) projection(cut = true) translate([0, 0, -4.2]) guard();
    color("#000") ann() ex(0.2) {
        dim_v(-32.2, 32.2, -10, "64.4", -1.7);
        dim_h(-1.7, 18, -40, "19.7", -32.2);
        leader([15, 24.5], [32, 30], "grip pads, 0.35 into the head", "left");
        label([-10, 42], "C: PLAN CUT AT Z = 4.2 (RAILS), 1:1", 0, "left");
    }
}
color("#000") ann() ex(0.2) label([-30, -145], "BLADE SCRAPER - v7 - guard grips the head, not the cap (body, cap, drawer as v6), dimensions in mm", 0, "left");

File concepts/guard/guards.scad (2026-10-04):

// Guard concepts for the v5 scraper. Body, cap and blade are v5's; only the guard changes.
include <v5lib.scad>

concept = 1;       // 0 = v4/v5 guard, 1 = wedge, 2 = raked, 3 = short sleeve
view = "assembly"; // assembly, guard, print, clash

// The guard slides on from the front. Inside it needs: the 62 mm blade slot the whole way (the
// cutting edge passes the mouth), the low "cap zone" over the cap walls (up to lip_top), and a
// narrower "crown zone" over the head (up to the nose slope). Outside is free: v4 hulled the
// whole thing into a box at the full mouth height.
function crown_hw(x) = hw(x) - dt + 0.6;          // head band + clearance
function cap_zone_top() = lip_top + guard_clear;
function crown_top(x) = x < 20 ? g_top(x) : max(g_top(x), h_at(x) + guard_clear);   // nose slope (the head is clipped to it) / head top

// interior; xm = mouth position at the bottom, xt = at the top (raked mouth when xt > xm)
module g_inner(xm, xt) {
    x1 = max(xm, xt) + 1;
    translate([-0.5, -g_hw, g_slot_z0]) cube([x1 + 0.5, 2 * g_hw, g_slot_z1 - g_slot_z0]);       // blade slot
    translate([x_front + 0.5, -g_hw, g_z0]) cube([x1 - x_front, 2 * g_hw, g_slot_z1 - g_z0]);  // relief below
    // ramp from the slot into the zones, then the zones themselves
    for (zone = [0, 1]) {
        hull() {
            translate([3.5, -g_hw, g_slot_z0]) cube([0.01, 2 * g_hw, g_slot_z1 - g_slot_z0]);
            zone_slice(x_front + 0.5, zone);
        }
        // follow the head's top: the nose slope to x = 20, then the loft
        let(xs = concat([x_front + 0.5], [for (x = [20:2:x1]) if (x < x1) x], [x1]))
            for (i = [0:len(xs) - 2]) hull() { zone_slice(xs[i], zone); zone_slice(xs[i + 1], zone); }
    }
}
module zone_slice(x, zone) let(w = zone == 0 ? g_cap_hw(x) : crown_hw(x), t = zone == 0 ? cap_zone_top() : crown_top(x))
    translate([x, -w, g_z0]) cube([0.01, 2 * w, t - g_z0]);

// outer section at x: a rounded slab over the blade and cap, and a rounded crown over the head
// Outer section at x: a rounded slab over the blade and cap walls, hulled with a crown in the
// head's own superellipse style. The crown's top runs as one straight wedge line from the nose
// back to x = 20 (2.4 mm over the nose slope there), so there is no step at the cap's front.
// per-concept outer settings (dynamic so every helper sees them): $gt wall, $ct crown wall over the head,
// $gn crown superellipse exponent, $gm crown half width beyond the inner crown zone
function wedge_top(x) = lookup(x, [[-1.1, g_slot_z1 + $gt], [x_front + 0.5, cap_zone_top() + $ct],
                                   [20, crown_top(20) + $ct], [40, crown_top(40) + $ct]]);
module g_section(x, inset = 0) let(
        nose = x < x_front + 0.5,
        // side and bottom lines run straight from the nose to the cap zone: no step at the sides
        zb = lookup(x, [[-1.1, g_slot_z0 - $gt], [x_front + 0.5, g_z0 - $gt], [40, g_z0 - $gt]]) + inset,
        zs = lookup(x, [[-1.1, g_slot_z1 + $gt], [x_front + 0.5, cap_zone_top() + $gt], [40, cap_zone_top() + $gt]]) - inset,
        zt = (nose ? wedge_top(x) : $open ? min(wedge_top(x), cap_zone_top() + $gt) : max(wedge_top(x), crown_top(x) + $ct)) - inset,
        ws = g_hw + $gt - inset, wc = crown_hw(x) + $gm - inset, r = 1.4)
    hull() {
        for (s = [-1, 1]) {
            translate([s * (ws - r), zb + r]) circle(r);
            translate([s * (ws - r), zs - r]) circle(r);
        }
        intersection() {
            polygon(se(2 * wc, zt, $gn, 64));
            translate([-wc, zb]) square([2 * wc, zt - zb]);
        }
    }
module g_slice(x, inset = 0) translate([x, 0, 0]) rotate([90, 0, 90]) linear_extrude(0.01) g_section(x, inset);

module g_outer(xm, xt) {
    x0 = -0.5 - $gt;
    xs = concat([for (x = [x0 + 1:1:max(xm, xt) - 0.5]) x], [max(xm, xt)]);
    hull() { g_slice(x0, 1); g_slice(xs[0]); }
    for (i = [0:len(xs) - 2]) hull() { g_slice(xs[i]); g_slice(xs[i + 1]); }
}
// raked mouth: plane through (xm, bottom) and (xt, top)
module rake_cut(xm, xt) let(zb = g_z0 - $gt - 1, zt = crown_top(xt) + $gt + 1)
    rotate([90, 0, 0]) linear_extrude(200, center = true)
        polygon([[xm, zb], [xt, zt], [xt + 40, zt], [xt + 40, zb]]);

module guard_c(xm, xt) {
    $fn = 32;
    difference() {
        g_outer(xm, xt);
        g_inner(xm, xt);
        rake_cut(xm, xt);
        // open top: the guard only needs to close over the exposed blade; behind it the head shows through
        if ($open) let(x1 = max(xm, xt) + 1) hull() for (x = [x_front + 0.5, x1])
            translate([x, -crown_hw(x), g_z0]) cube([0.01, 2 * crown_hw(x), 40]);
        // lead-in chamfer at the mouth: each zone's opening flares by mouth_chamfer
        if (xm == xt) for (zone = [0, 1]) let(zp0 = g_z0 - $gt - 1, zp1 = crown_top(xt) + $gt + 1,
                                x = zone == 0 ? xm : xm + (xt - xm) * (cap_zone_top() - zp0) / (zp1 - zp0),
                                w = zone == 0 ? g_cap_hw(x) : crown_hw(x), t = zone == 0 ? cap_zone_top() : crown_top(x))
            hull() {
                zone_slice(x - mouth_chamfer - 0.5, zone);
                translate([x + 0.5, -(w + mouth_chamfer + 0.5), g_z0 - mouth_chamfer - 0.5])
                    cube([0.01, 2 * (w + mouth_chamfer + 0.5), t - g_z0 + 2 * mouth_chamfer + 1]);
            }
    }
    // friction bumps on the cap walls, above the blade slot (as v4)
    for (s = [-1, 1]) translate([x_front + 4, s * g_cap_hw(x_front + 4), (g_slot_z1 + lip_top) / 2]) sphere(0.75, $fn = 16);
}

// ---- concepts: [mouth x at the bottom, mouth x at the top] ----
mouths = [[18, 18], [18, 18], [15.5, 21], [12, 12], [18, 18], [18, 18], [15, 15]];
// [wall, crown wall, exponent, crown margin]; concept 4 = slim wedge
outers = [[], [guard_t, 2.4, 8, 3, false], [guard_t, 2.4, 8, 3, false], [guard_t, 2.4, 8, 3, false], [1.2, 1.6, 10, 3.5, false], [1.2, 1.2, 10, 3.5, true], [1.2, 1.6, 10, 3.5, false]];
module guard_sel(c) {
    if (c == 0) guard();
    else let($gt = outers[c][0], $ct = outers[c][1], $gn = outers[c][2], $gm = outers[c][3], $open = outers[c][4]) guard_c(mouths[c][0], mouths[c][1]);
}

module model(c = concept, v = view) {
    if (v == "guard") guard_sel(c);
    else if (v == "clash") { intersection() { guard_sel(c); body(); } intersection() { guard_sel(c); blade(); } }
    else {
        color("#8fb3d9") body(); color("#e8a33d") cap(); blade(); color("#5cb88a") drawer();
        color("#5d9e72") guard_sel(c);
    }
}
if (view != "none") model();

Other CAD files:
prints/v7/scraper-v7-guard.3mf
prints/v7/scraper-v7-guard-test.3mf
drawings/v7/scraper-v7.stl
drawings/v6/assembled-guard-scraper-v6.stl
drawings/v1/assembled-guard-scraper-v1.stl
drawings/v3/assembled-guard-scraper-v3.stl
drawings/v4/assembled-guard-scraper-v4.stl
concepts/guard/v5lib.scad
concepts/v5/concepts.scad
concepts/v5/v4lib.scad
drawings/drawing-v1.scad
drawings/drawing-v2.scad
drawings/drawing-v3.scad
drawings/drawing-v4.scad
drawings/drawing-v5.scad
drawings/drawing-v6.scad
drawings/v2/guard-scraper-v2.stl
drawings/v2/scraper-v2.stl
drawings/v3/guard-scraper-v3.stl
drawings/v3/scraper-v3.stl
drawings/v4/body-scraper-v4.stl
drawings/v4/test-scraper-v4.stl
drawings/v5/drawer-test-scraper-v5.stl
drawings/v5/guard-scraper-v5.stl
drawings/v5/test-scraper-v5.stl
drawings/v6/body-scraper-v6.stl
drawings/v6/cap-scraper-v6.stl
drawings/v6/drawer-scraper-v6.stl
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

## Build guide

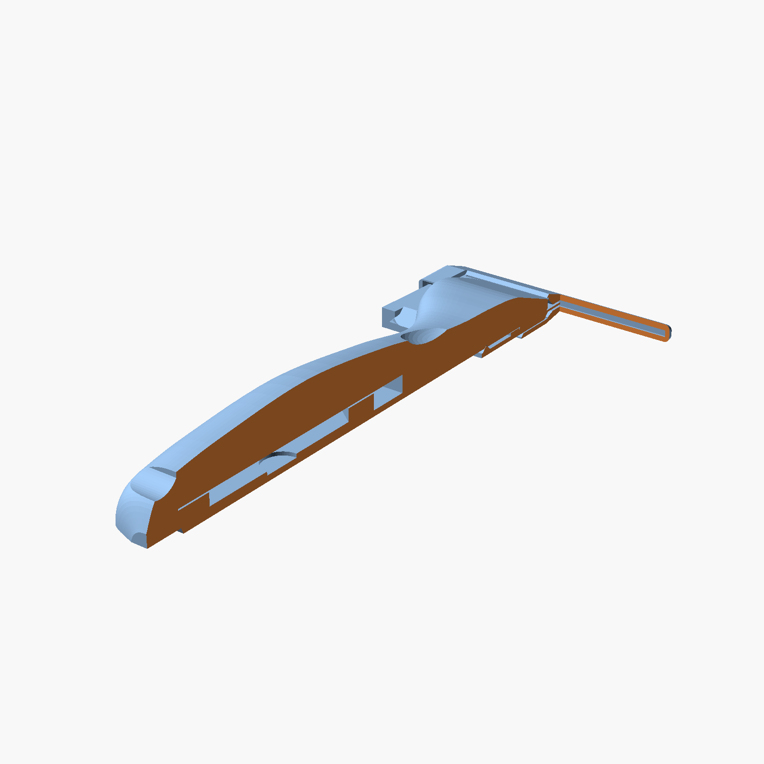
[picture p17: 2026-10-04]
drawings/v7/assembled-guard-section-3d.png

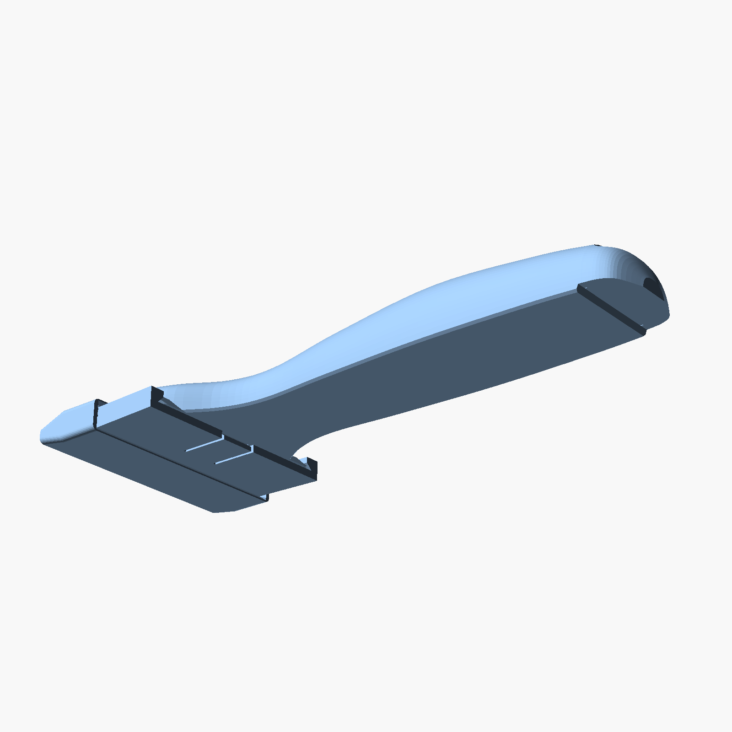
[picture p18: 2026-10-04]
drawings/v7/assembled-guard-iso-bottom.png

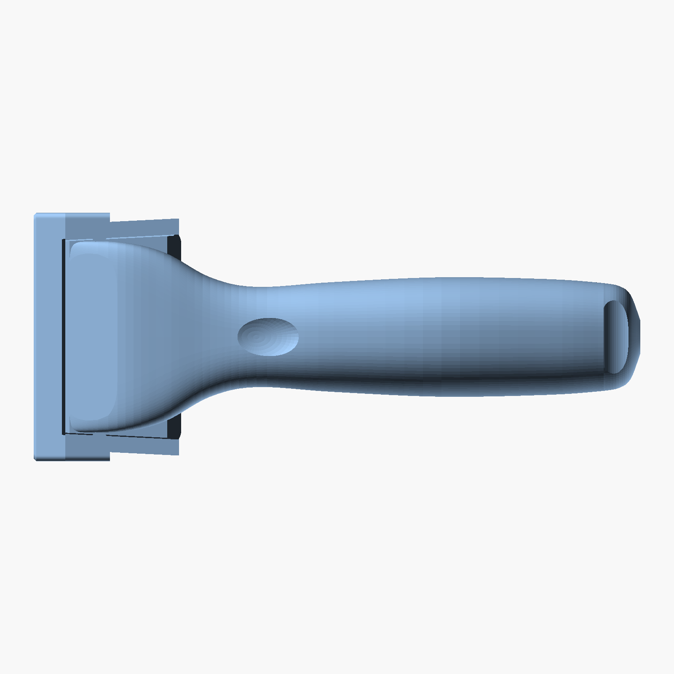
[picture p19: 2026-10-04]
drawings/v7/assembled-guard-top.png

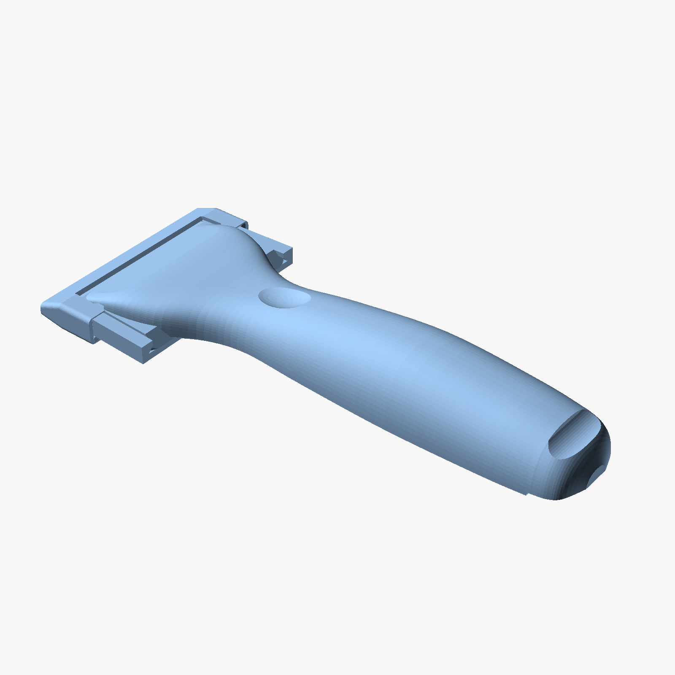
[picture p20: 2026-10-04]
drawings/v7/assembled-guard-iso-top.png

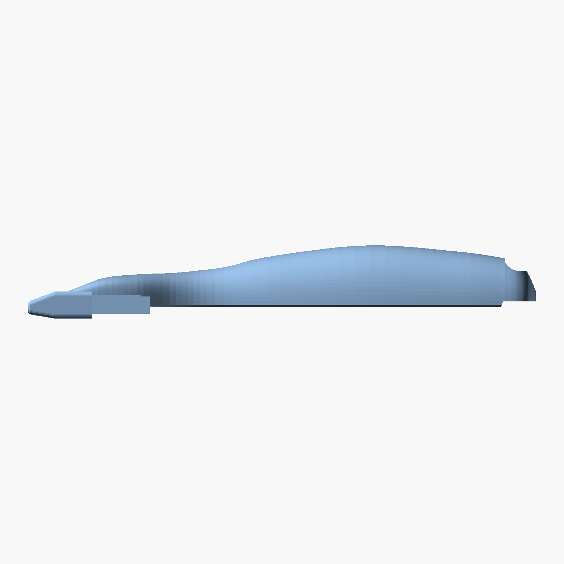
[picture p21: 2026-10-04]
drawings/v7/assembled-guard-side.png

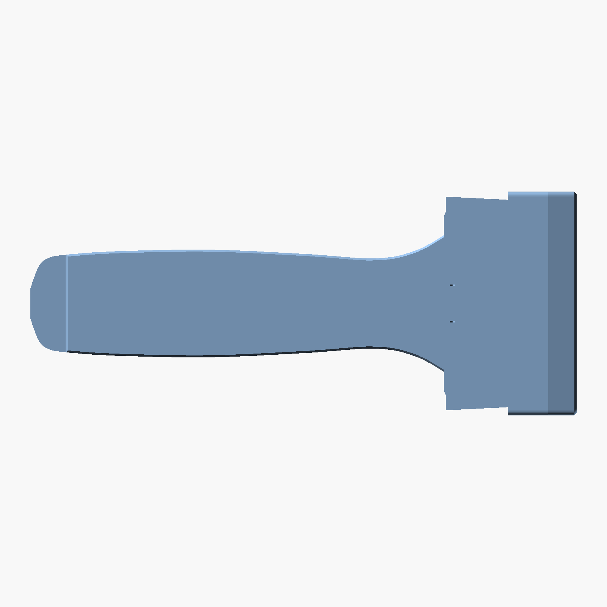
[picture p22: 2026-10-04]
drawings/v7/assembled-guard-bottom.png

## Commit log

2026-10-03 v1: razor scraper for a trapezoid utility blade
    Body with a rising D-section handle, slide-on cap that holds the blade
    (pegs in the notches, 45° dovetails, snap tab), slide-on guard and a
    test-fit piece. Includes the design brief, drawings/renders and the
    gcode the parts were printed with.
    [assembled-guard-scraper-v1.stl, assembly-scraper-v1.stl, drawing-v1.scad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]
2026-10-03 v2: guard's blade slot runs through to the mouth
    The mouth was 59.1 mm wide, narrower than the 61 mm cutting edge that has
    to pass through it, so the guard couldn't slide on. Friction bumps moved
    above the slot.
    [assembled-guard-scraper-v2.stl, drawing-v2.scad, guard-scraper-v2.stl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]
2026-10-03 v3: guard clears the cap's elephant's foot
    Guard walls relieved to the slot width below the blade plane, and a
    0.8 mm lead-in chamfer at the mouth (it prints mouth-down). Adds
    tools/make_3mf.py, which builds a Creality Print project with the
    settings of a sliced gcode, and scraper-guard.3mf for reprinting the
    guard to fit the printed v1.
    [assembled-guard-scraper-v3.stl, drawing-v3.scad, guard-scraper-v3.stl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]
2026-10-03 v4: tapered dovetails so sliding the cap on no longer drags the blade out
    Head and cap dovetails widen 0.05 mm per mm per side towards the back
    (cap 58.5 mm at the front, 61.5 mm at the back). The lips only clamp in
    the last 2 mm of travel. The guard follows the wider cap. Adds the
    test-fit print project. report.html (generated by report.py) is ignored.
    [assembled-guard-scraper-v4.stl, assembly-scraper-v4.stl, body-scraper-v4.stl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]
2026-10-04 v5: shorter handle with a blade drawer and a head that flows into the grip
    New handle, 155.5 mm overall (was 177), 31 x 19 mm palm swell, drawn as
    one smooth spline. Above the cap the head is lofted into the grip; below
    3.6 mm and under the guard it is v4's exactly, so cap and guard are
    unchanged. A drawer for 5 spare blades slides in from the butt and clicks
    shut on two side-flexing arms. Adds the drawer test-fit print project,
    scraper_v5.stl (all four parts) and the v5 concept study.
    [assembled-guard-scraper-v5.stl, assembly-open-scraper-v5.stl, assembly-scraper-v5.stl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]
2026-10-04 Tidy the folder: print files in prints/vN, concepts in concepts/
    Root keeps only the models (scraper-vN.scad), BRIEF.md and REVIEW.md, as
    the report script expects. Print files move to prints/v1, v3, v4 and v5
    by the version they belong to; scraper.stl becomes
    prints/v3/scraper-v1-with-v3-guard.stl and scraper_vN.stl becomes
    prints/vN/scraper-vN.stl. The v5 concept study moves to concepts/v5.
    [concepts.scad, scraper-body.stl, scraper-cap.stl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]
2026-10-04 v6: open-top guard to match the v5 head
    The guard closes only over the exposed blade; behind the nose it is a
    frame whose rails hook over the cap walls, with the head showing
    through. 8.4 mm tall (was 13.7), 1.2 mm walls, 4.6 g (was 7.7). Inside
    fit unchanged: blade slot, cap clearance, friction bumps, mouth lead-in.
    Body, cap and drawer as v5.
    Adds prints/v6 (all parts as STL and a Creality Print project, the
    guard on its own, and a guard test-fit project) and the guard concept
    study in concepts/guard.
    [assembled-guard-scraper-v6.stl, assembly-open-scraper-v6.stl, assembly-scraper-v6.stl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]
2026-10-04 Add README with renders of v6
    Short description, features, print settings, how to change a blade,
    a versions table linking to the GitHub releases, and four renders in
    images/. tools/readme_renders.py re-renders them for a new version;
    the README notes it should be updated with every release.
2026-10-04 v6: print the guard on its nose (fix in place)
    Printed on its open end, the guard's open-top front edge and the end of
    its blade slot were 51 and 62 mm bridges. It now stands on a flat nose
    (0.6 mm bed chamfer) with the open end up, so every inside surface
    widens going up: no supports and no bridges. Geometry and fit are
    otherwise unchanged. Print files, renders, README and review log
    updated.
    [assembled-guard-scraper-v6.stl, guard-scraper-v6.stl, guard-test-scraper-v6.stl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]
2026-10-04 Removed dangerous usage advice from README
    Removed 'print beds' from the description of the scraper.
2026-10-04 README: v6 test-print result and print timelapse
    v6 fits, except the guard, which snaps to one side instead of sliding
    on straight. Adds a timelapse GIF of the v6 parts printing.
2026-10-04 License under CC BY-NC-SA 4.0
    Add the licence text and a Licence section to the README. Also ignore
    the local printables/ folder used to prepare the Printables listing.
2026-10-04 README: link the Printables listing
2026-10-04 Revise README
    Updated the description of the current version and improved clarity in the instructions for fitting a blade.
2026-10-04 v7: guard grips the head, not the cap
    Taking the guard off often pulled the cap and blade with it, sometimes
    out of the guard: its friction bumps pressed on the cap walls, and the
    cap slides off in the same direction the guard is pulled. The bumps are
    gone; a pad on each rail presses 0.35 mm into the head's flank above
    the cap, and the guard stays 0.3 mm clear of the cap all round.
    Guard only: body, cap and drawer are v6's. Adds prints/v7 (all parts,
    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
    [assembled-guard-scraper-v7.stl, drawing-v7.scad, guard-scraper-v7.stl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]
2026-10-04 v7: test-printed, mark approved
    The v7 guard was printed and fitted: it slides on and holds, and comes
    off a little easily but acceptably. README status line and the review
    log updated to match.
